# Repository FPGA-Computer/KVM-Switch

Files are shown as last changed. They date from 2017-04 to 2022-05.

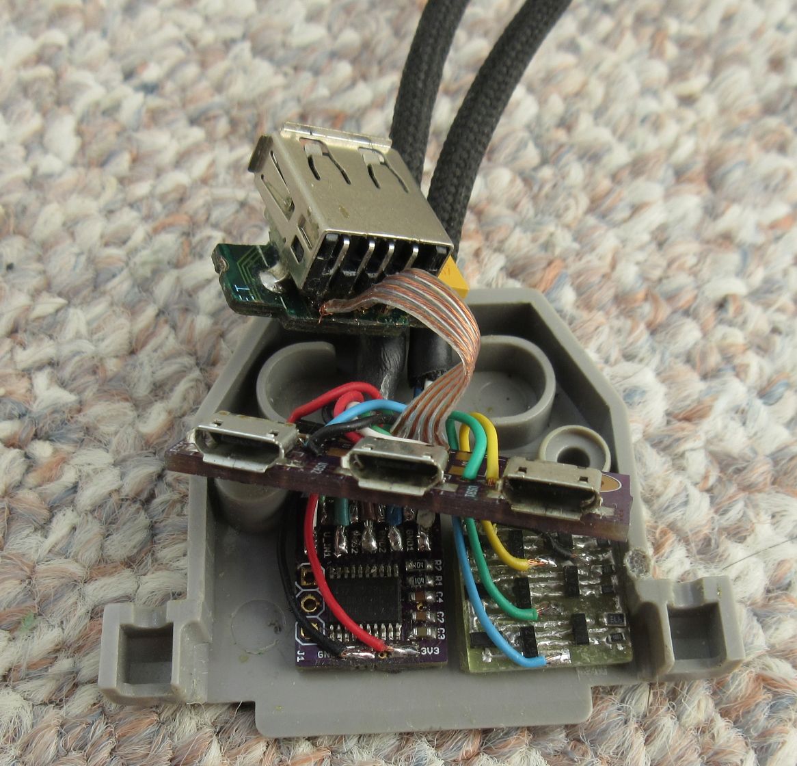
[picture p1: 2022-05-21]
Hardware/KVM boards.jpg

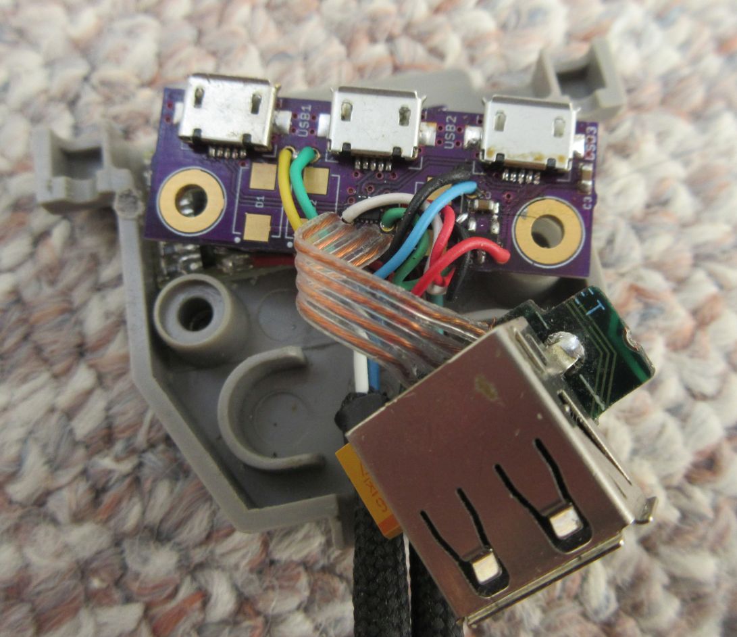
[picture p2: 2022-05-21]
Hardware/KVM boards - top.jpg

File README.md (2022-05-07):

KVM Switch
built from $5 HDMI switch + custom hardware

Details: https://hw-by-design.blogspot.com/2018/07/low-cost-kvm-switch.html

Hardware/ - Eagle CAD schematic, PCB, Sketchup 3D model (zipped)
Firmware/ - STM8S003 firmware source code for hotkey
KVM-Hotkey/ - initial test code I used during development.  
Included here for archive and completeiness because of my hosting changes.

Firmware written by me are licensed under GPL 3.0. 
Additional incorporated code are under their own licenses.

Hardware is licensed under CC BY-4.0

https://creativecommons.org/licenses/by/4.0/

Updates: change to Right CTRL key as hotkey.

Updates:

- Optional active or'ing circuit to replace Schottky diodes for lower voltage drops.

Or'ing circuit imspired by RPi 3 Model B rev. 1.2 USB power circuit. The matching transistor pair is
not needed - verified by simulation.  Voltage drop (roughly 50mV @0.5A). The circuit can share current
from multiple USB supplies.

- new USB Mux-v0.2 PCB layout with larger wiring pads, pads for optional or'ing circuit

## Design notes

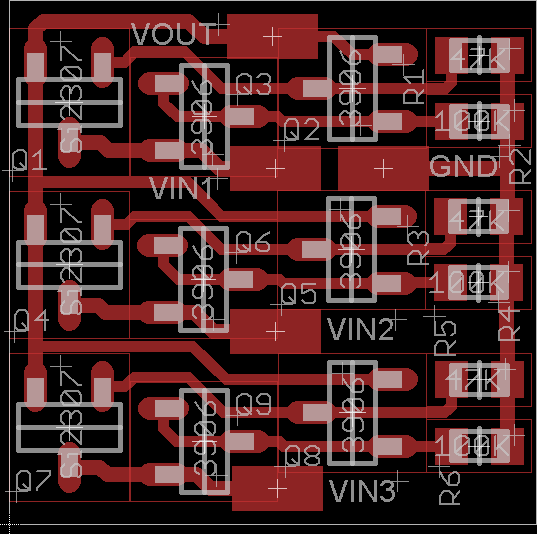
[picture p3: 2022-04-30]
Hardware/Acive Or'ing (optional)/active or'ing PCB.png

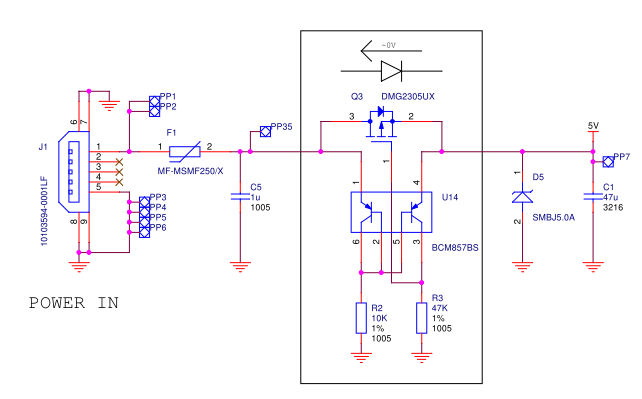
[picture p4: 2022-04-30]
Hardware/Acive Or'ing (optional)/RPi3 Model B or'ing circuit.png

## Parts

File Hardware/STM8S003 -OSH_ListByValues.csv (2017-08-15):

Qty | Value | Part Num | Package | Parts
2 | 0.1uF | 0.1uF X7R 0603 | CAPC1608X92N | C3, C4
1 | 1uF | 1uF X5R/X7R 0603 | CAPC1608X92N | C2
2 | 100K | 100K 0603 | RESC1608X55N | R1, R2
1 | STM8S003F3 | STM8S003F3 | TSSOP20 | U1
1 | SWIM Debug | 1x3 header for debugger | 1X03 | J1
1 | PCB | Ordering: https://oshpark.com/shared_projects/IDmovVvi

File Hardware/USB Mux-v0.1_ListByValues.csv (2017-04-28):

Qty | Value | Part Num | Package | Parts
3 |  | SMT MICRO USB CONNECTOR | USB-AB-MICRO-SMD_V03_SMT | USB1, USB2, USB3
1 | 0.1uF | 0U1 0603 | CAPC1608X92N | C1
2 | 1uF | 1UF 0603 | CAPC1608X92N | C2, C3
3 | MBRS140 | MBRS140 | DIOM5436X265N | D1, D2, D3
1 | NCN9252 | NCN9252 | UQN12 | U1
1 | XC6206P332MR | XC6206P332MR | SOT95P280X135-3N | U2 | Alternative: MCP1700T-3302E/TT
1 | PCB |  |  |  | https://oshpark.com/shared_projects/noy8f3xy

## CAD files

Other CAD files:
Firmware/hotkey.stp
Firmware/hotkey_Programmer/hotkey_STVP.stp
KVM-Hotkey/hotkey.stp

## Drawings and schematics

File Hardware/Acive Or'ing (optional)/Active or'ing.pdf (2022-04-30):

A

A

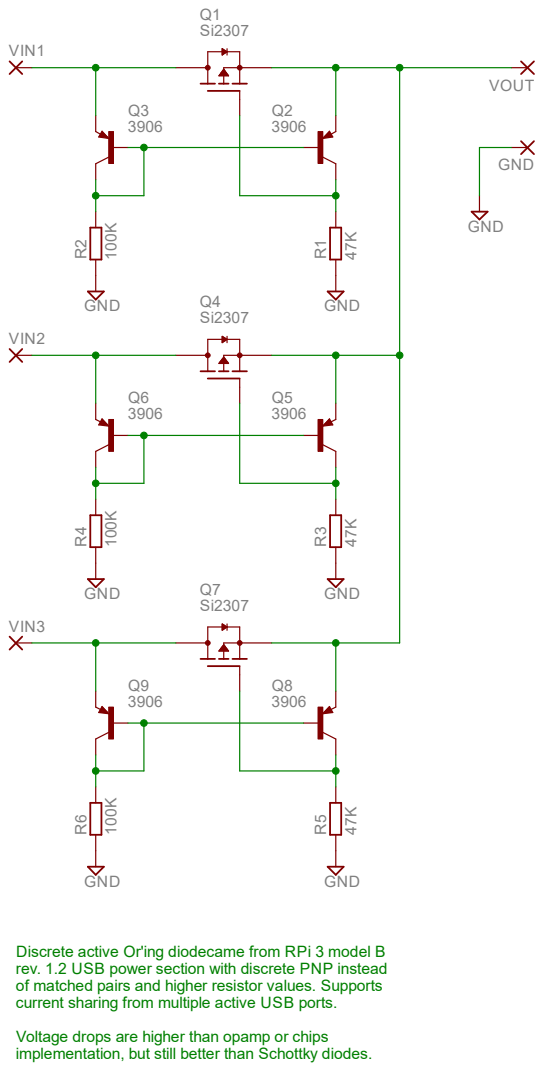
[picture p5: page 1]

Discrete active Or'ing diodecame from RPi 3 model B
rev. 1.2 USB power section with discrete PNP instead
of matched pairs and higher resistor values. Supports
current sharing from multiple active USB ports.

Copyright 2022 (c) by K. C. Lee
Licensed under CC BY-4.0

Voltage drops are higher than opamp or chips
implementation, but still better than Schottky diodes.

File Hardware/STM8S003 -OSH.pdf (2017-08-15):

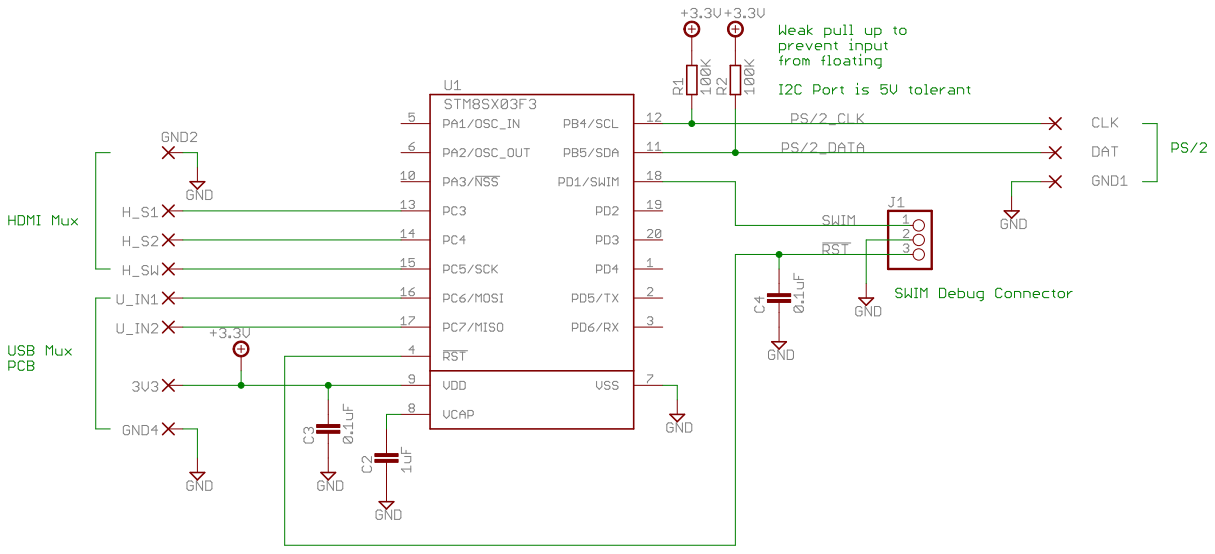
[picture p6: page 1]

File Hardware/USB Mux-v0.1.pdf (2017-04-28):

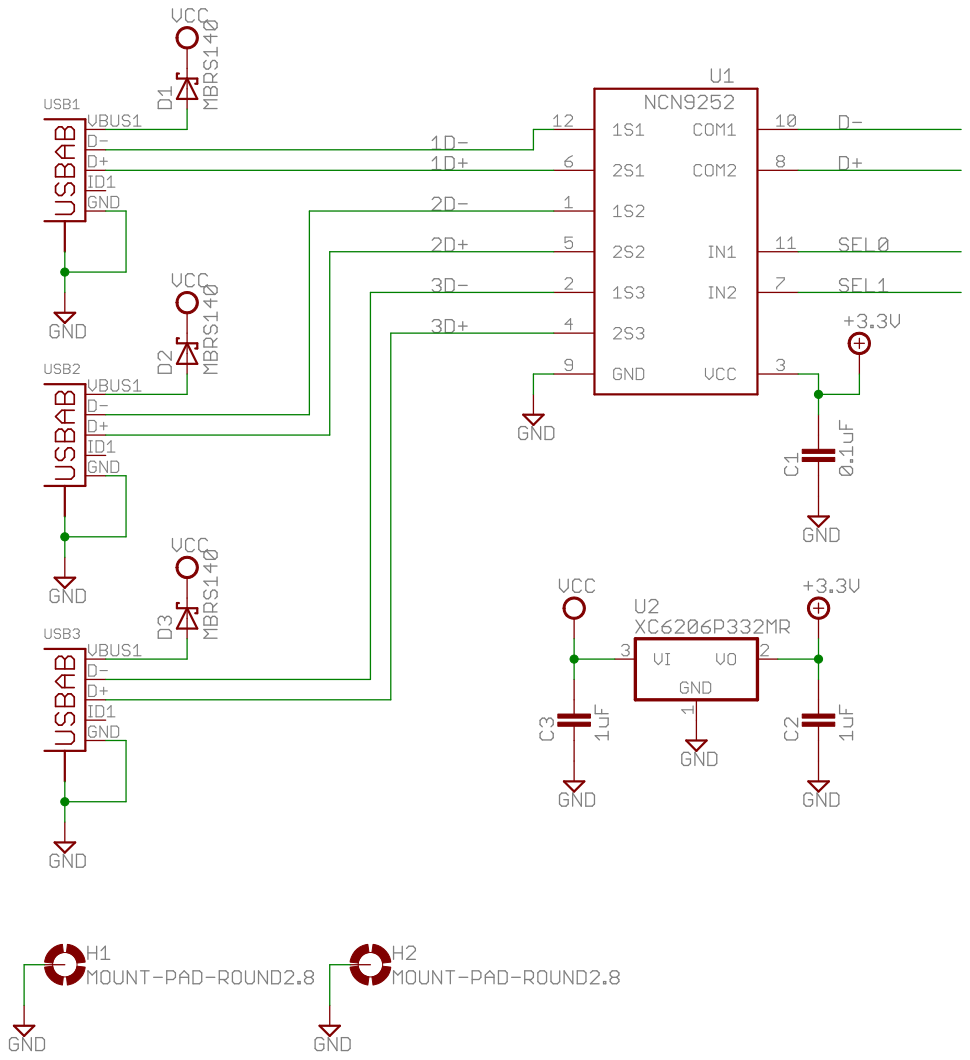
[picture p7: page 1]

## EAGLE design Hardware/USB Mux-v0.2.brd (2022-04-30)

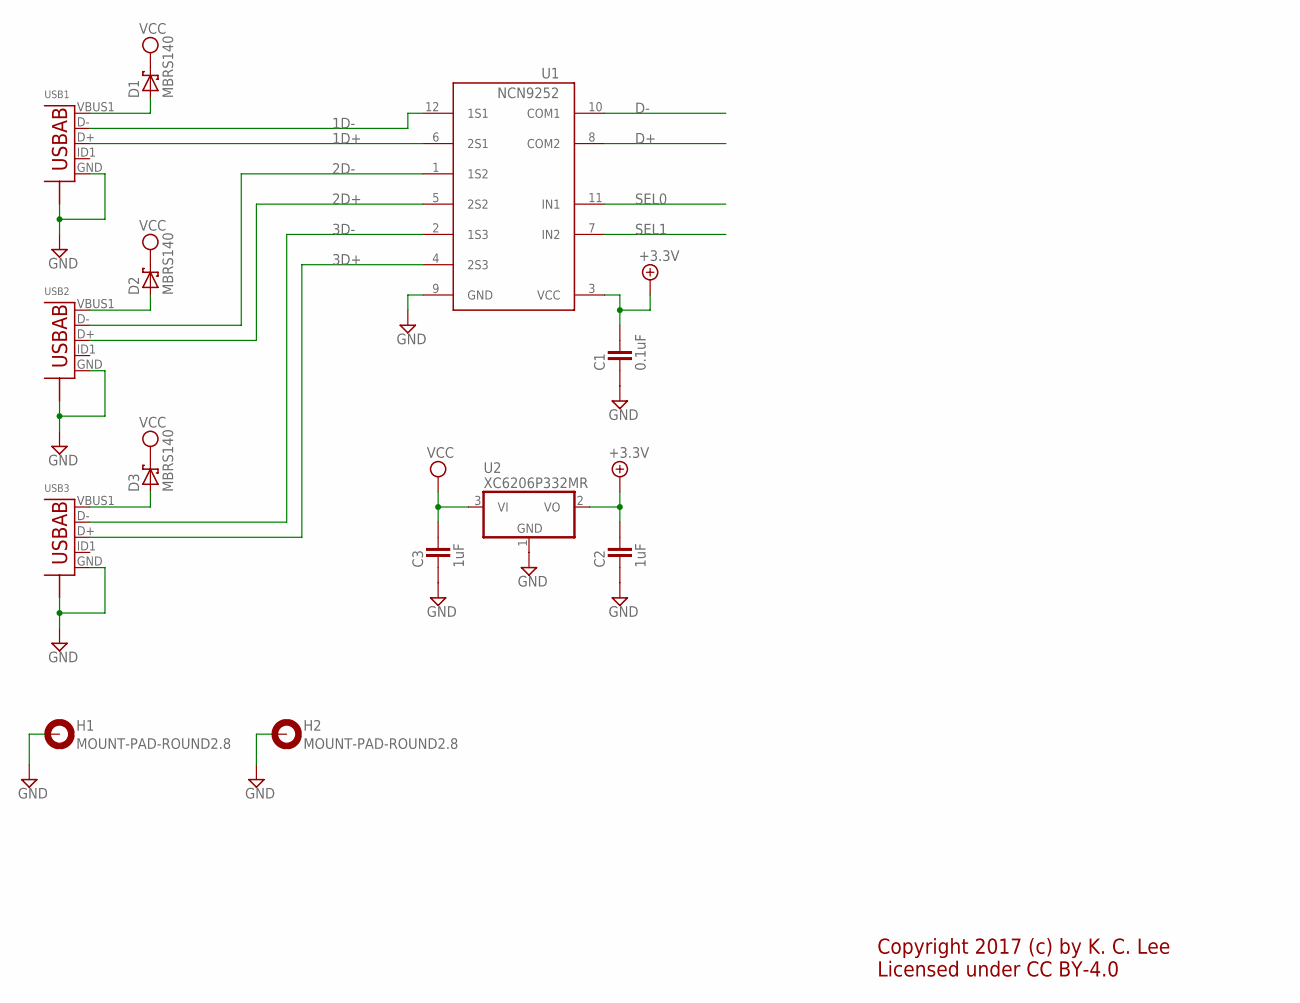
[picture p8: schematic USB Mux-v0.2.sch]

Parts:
C1: 0.1uF; CAPC1608X92N; PARTNO 0U1 0603
C2, C3: 1uF; CAPC1608X92N; PARTNO 1UF 0603
D1, D2, D3: MBRS140; DIOM5436X265N; PARTNO MBRS140
H1, H2: MOUNT-PAD-ROUND2.8; 2,8-PAD; PARTNO *
U1: NCN9252; UQN12; PARTNO NCN9252
U2: XC6206P332MR; SOT95P280X135-3N; PARTNO XC6206P332MR
USB1, USB2, USB3: USB-ABBG-ORG; USB-AB-MICRO-SMD_V03_SMT; PARTNO SMT MICRO USB CONNECTOR

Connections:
1D+: U1.6 (2S1), USB1.D+
1D-: U1.12 (1S1), USB1.D-
2D+: U1.5 (2S2), USB2.D+
2D-: U1.1 (1S2), USB2.D-
3D+: U1.4 (2S3), USB3.D+
3D-: U1.2 (1S3), USB3.D-
+3.3V: C1.2, C2.2, U1.3 (VCC), U2.2 (VO)
D+: U1.8 (COM2)
D-: U1.10 (COM1)
GND: C1.1, C2.1, C3.1, H1.B2,8, H2.B2,8, U1.9 (GND), U2.1 (GND), USB1.GND, USB1.S1 (S), USB1.S2 (S), USB1.S3 (S), USB1.S4 (S), USB2.GND, USB2.S1 (S), USB2.S2 (S), USB2.S3 (S), USB2.S4 (S), USB3.GND, USB3.S1 (S), USB3.S2 (S), USB3.S3 (S), USB3.S4 (S)
unnamed: D3.A, USB3.VBUS1 (VBUS)
unnamed: D2.A, USB2.VBUS1 (VBUS)
unnamed: D1.A, USB1.VBUS1 (VBUS)
SEL0: U1.11 (IN1)
SEL1: U1.7 (IN2)
VCC: C3.2, D1.K, D2.K, D3.K, U2.3 (VI)

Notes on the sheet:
Copyright 2017 (c) by K. C. Lee Licensed under CC BY-4.0

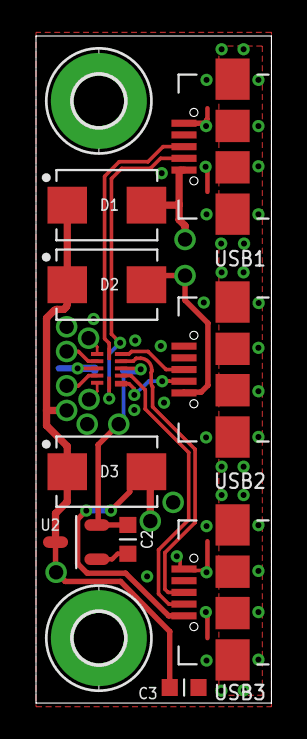
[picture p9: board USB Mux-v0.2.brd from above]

Board: 2 copper layers, 13.1 x 37.1 mm, 13 parts (1 on the bottom side), 12 nets.

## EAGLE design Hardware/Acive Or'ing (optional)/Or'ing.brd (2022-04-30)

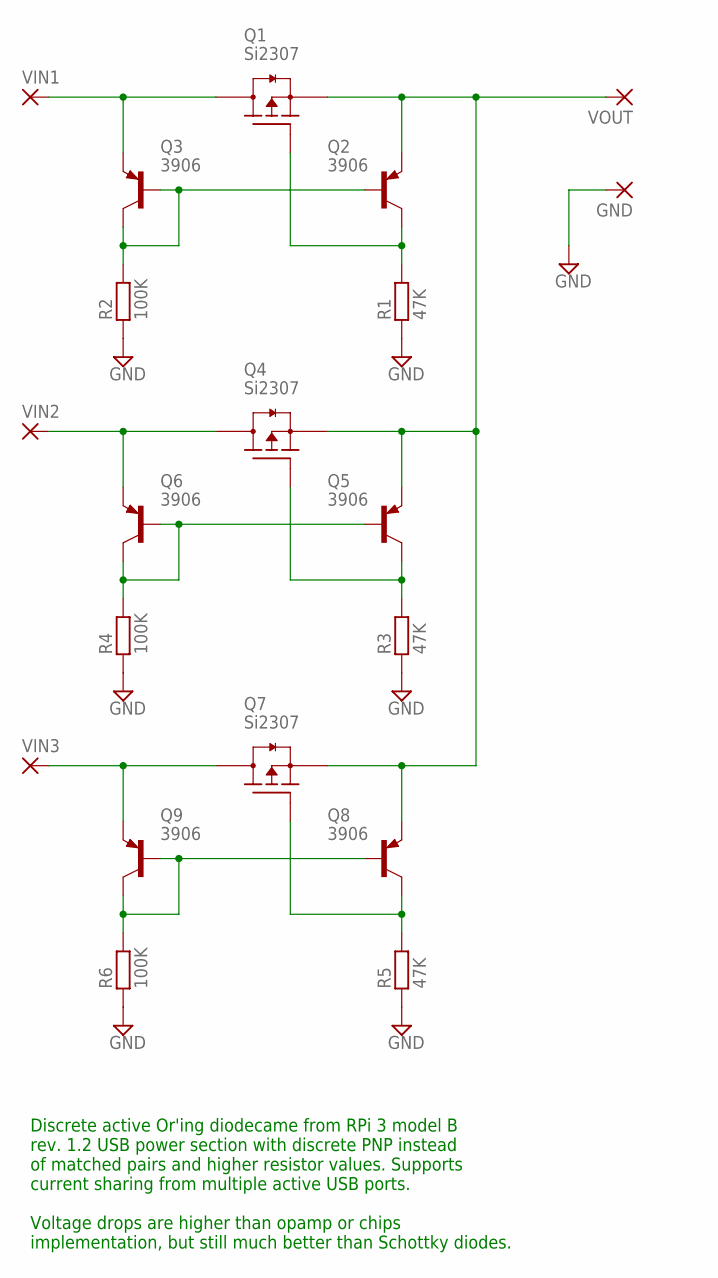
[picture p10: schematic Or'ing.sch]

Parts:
GND: SMD2; SMD1,27-2,54
Q1, Q4, Q7: Si2307; SOT95P280X135-3N
Q2, Q3, Q5, Q6, Q8, Q9: 3906; SOT95P280X135-3N
R1, R3, R5: 47K; RESC1608X55N
R2, R4, R6: 100K; RESC1608X55N
VIN1, VIN2, VIN3: SMD2; SMD1,27-2,54
VOUT: SMD2; SMD1,27-2,54

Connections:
GND: GND.1, R1.1, R2.1, R3.1, R4.1, R5.1, R6.1
unnamed: Q1.2 (S), Q2.2 (E), Q4.2 (S), Q5.2 (E), Q7.2 (S), Q8.2 (E), VOUT.1
unnamed: Q1.3 (D), Q3.2 (E), VIN1.1
unnamed: Q1.1 (G), Q2.3 (C), R1.2
unnamed: Q2.1 (B), Q3.1 (B), Q3.3 (C), R2.2
unnamed: Q4.3 (D), Q6.2 (E), VIN2.1
unnamed: Q4.1 (G), Q5.3 (C), R3.2
unnamed: Q5.1 (B), Q6.1 (B), Q6.3 (C), R4.2
unnamed: Q7.3 (D), Q9.2 (E), VIN3.1
unnamed: Q7.1 (G), Q8.3 (C), R5.2
unnamed: Q8.1 (B), Q9.1 (B), Q9.3 (C), R6.2

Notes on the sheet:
Discrete active Or'ing diodecame from RPi 3 model B rev. 1.2 USB power section with discrete PNP instead of matched pairs and higher resistor values. Supports current sharing from multiple active USB ports. Voltage drops are higher than opamp or chips implementation, but still much better than Scho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

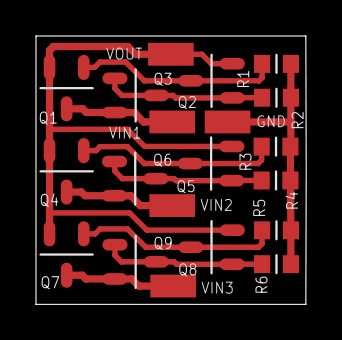
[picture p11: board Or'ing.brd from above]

Board: 2 copper layers, 15.0 x 14.9 mm, 20 parts (0 on the bottom side), 11 nets.

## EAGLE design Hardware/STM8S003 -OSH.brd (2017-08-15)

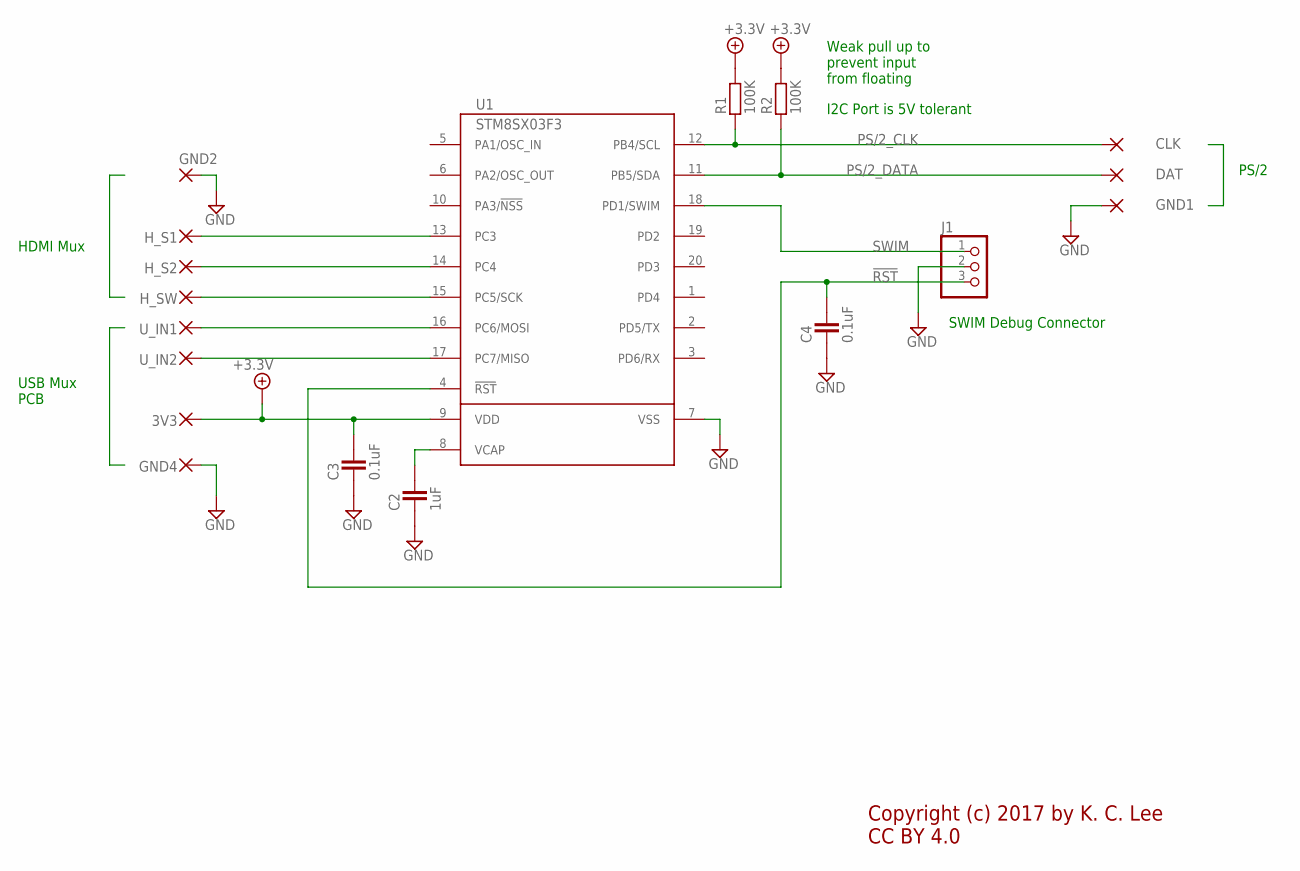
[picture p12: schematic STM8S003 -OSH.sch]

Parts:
3V3: SMD2; SMD1,27-2,54
C2: 1uF; CAPC1608X92N
C3, C4: 0.1uF; CAPC1608X92N
CLK: SMD2; SMD1,27-2,54
DAT: SMD2; SMD1,27-2,54
GND1, GND2, GND4: SMD2; SMD1,27-2,54
H_S1, H_S2: SMD2; SMD1,27-2,54
H_SW: SMD2; SMD1,27-2,54
J1: PINHD-1X3; 1X03
R1, R2: 100K; RESC1608X55N
U1: STM8SX03F3; TSSOP20
U_IN1, U_IN2: SMD2; SMD1,27-2,54

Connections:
!RST: C4.2, J1.3, U1.4 (!RST)
+3.3V: 3V3.1, C3.2, R1.2, R2.2, U1.9 (VDD)
GND: C2.1, C3.1, C4.1, GND1.1, GND2.1, GND4.1, J1.2, U1.7 (VSS)
unnamed: C2.2, U1.8 (VCAP)
unnamed: U1.17 (PC7/MISO), U_IN2.1
unnamed: U1.16 (PC6/MOSI), U_IN1.1
unnamed: H_SW.1, U1.15 (PC5/SCK)
unnamed: H_S1.1, U1.13 (PC3)
unnamed: H_S2.1, U1.14 (PC4)
PS/2_CLK: CLK.1, R1.1, U1.12 (PB4/SCL)
PS/2_DATA: DAT.1, R2.1, U1.11 (PB5/SDA)
SWIM: J1.1, U1.18 (PD1/SWIM)

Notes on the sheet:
Copyright (c) 2017 by K. C. Lee CC BY 4.0
HDMI Mux
USB Mux PCB
PS/2
SWIM Debug Connector
Weak pull up to prevent input from floating
I2C Port is 5V tolerant

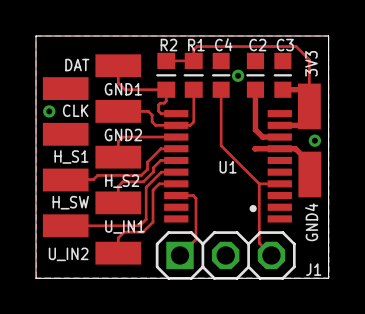
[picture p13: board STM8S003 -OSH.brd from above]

Board: 2 copper layers, 16.3 x 13.5 mm, 18 parts (0 on the bottom side), 12 nets.

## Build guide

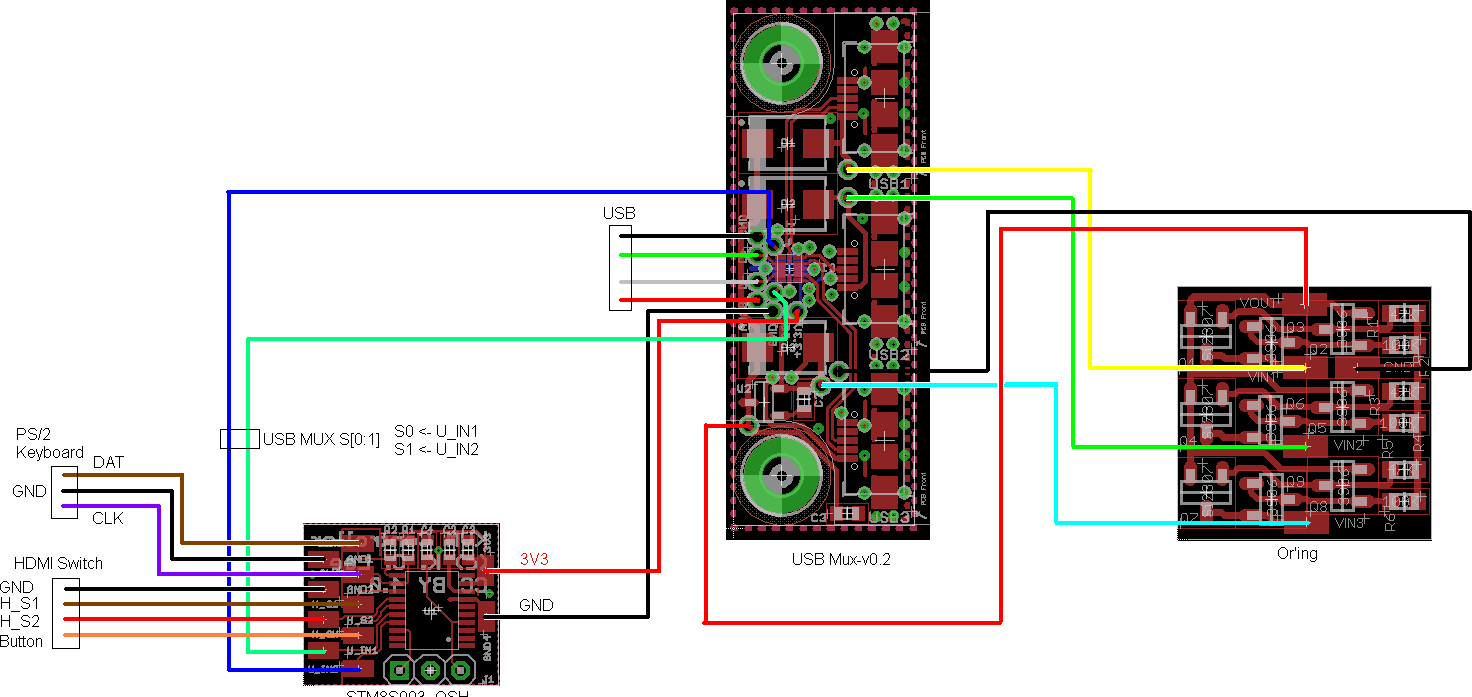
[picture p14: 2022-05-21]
Hardware/Wiring diagram.png

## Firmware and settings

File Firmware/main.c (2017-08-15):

/*
 * main.c
 *
 * Created: April-28-17, 5:42:00 PM
 *  Author: K. C. Lee
 * Copyright (c) 2017 by K. C. Lee
 
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
 If not, see http://www.gnu.org/licenses/gpl-3.0.en.html 
 */ 

#include "hardware.h"

void main(void)
{
	Init_Hardware();
	
	while(1)
	{
		PS2_Task();
	}
}

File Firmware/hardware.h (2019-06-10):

/*
 * hardware.h
 *
 * Created: 22/12/2016 6:03:25 AM
 *  Author: K. C. Lee
 * Copyright (c) 2016 by K. C. Lee
 
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
 If not, see http://www.gnu.org/licenses/gpl-3.0.en.html 
 */ 

#ifndef HARDWARE_H_
#define HARDWARE_H_

#ifndef __CSMC__
#define __CSMC__
#endif
#define STM8S003

#include "stm8s.h"
//#include <stdio.h>

// STM8S003F3P6
enum _PA { PA1=0x02, PA2=0x04, PA3=0x08 };
enum _PB { PB4=0x10, PB5=0x20 };
enum _PC { PC3=0x08, PC4=0x10, PC5=0x20, PC6=0x40, PC7=0x80 };
enum _PD { PD1=0x02, PD2=0x04, PD3=0x08, PD4=0x10, PD5=0x20, PD6=0x40 };

#include "irq.h"

#define PS2_CLK									PB4
#define PS2_DATA								PB5
#define PS2_PORT								GPIOB

#define HDMI_S1									PC3
#define HDMI_S2									PC4

#define HDMI_SW									PC5

#define USB_IN1									PC6
#define USB_IN2									PC7
#define HDMI_PORT								GPIOC

#define HDMI_NO_CONNECT					0x01
#define USB_NO_CONNECT					0x00

#define HDMI_SEL_MASK						(HDMI_S1 | HDMI_S2)
#define USB_SEL_MASK						(USB_IN1 | USB_IN2)

#define HDMI_SHIFT							3
#define USB_SHIFT								6

#define PS2_KBD									0x40
#define PS2_CMD									0x00

#define PS2_KBD_BITS						10
#define PS2_CMD_BITS						11

#define PS2_BIT_TIMEOUT					1500		// us

enum Key_States
{
	PS2_Idle = 0,
	PS2_KBD_1 = PS2_KBD+1,
	PS2_KBD_LAST = PS2_KBD_1+PS2_KBD_BITS,
	PS2_CMD_1 = PS2_CMD+1,
	PS2_CMD_LAST = PS2_CMD_1+PS2_CMD_BITS
};

enum Hotkey_States
{
	HK_Idle,
	HK_KeyMake_1,
	HK_KeyBreak_1,
	HK_KeyMake_2
};

enum KeyAttrib
{
	Key_Regular = 0x00,
	Key_Release = 0x01,
	Key_Extend	= 0x02
};

typedef struct
{
	volatile	uint16_t	ScanCode;
						uint8_t 	State;
						uint8_t		Attrib;
	volatile 	uint8_t		Avail;
} KBD_States;

#define PS2_KBD_CODE_EXTENDED   0xe0
#define PS2_KBD_CODE_RELEASE    0xf0

// CTRL
#define HOTKEY_SCANCODE					0x14

#define RCTRL		// Hotkey: Right CRTL

#ifdef RCTRL		// Hotkey: Right CRTL
#define HOTKEY_MAKE							((ScanCode == HOTKEY_SCANCODE) && (Hotkeys.KeyAttr==Key_Extend))
#define HOTKEY_RELEASE					((ScanCode == HOTKEY_SCANCODE) && (Hotkeys.KeyAttr==(Key_Extend|Key_Release)))
#else						// Hotkey: Left CRTL
#define HOTKEY_MAKE							((ScanCode == HOTKEY_SCANCODE) && !Hotkeys.KeyAttr)
#define HOTKEY_RELEASE					((ScanCode == HOTKEY_SCANCODE) && (Hotkeys.KeyAttr==Key_Release))
#endif

#define HOTKEY_RELEASE_DELAY		ms_TO_TICKS(250)
#define HOTKEY_WAIT_DELAY				ms_TO_TICKS(200)
#define HOTKEY_USB_WAIT					ms_TO_TICKS(50)
#define HDMI_SW_DELAY						ms_TO_TICKS(100)

typedef struct
{
	uint8_t State;
	uint8_t KeyAttr;
} Hotkey_State;

#define TIM4_PSCR								3
#define TIM4_ARR 								200
#define MILLI_DIVIDER_RELOAD		100

// 16MHz/2^TIM4_PSCR/TIM4_ARR = 10kHz (100us per tick)
// 10kHz/MILLI_DIVIDER_RELOAD = 100Hz (10ms per tick)

// Minimum delay
#define us_TO_TICKS(X)					((X)/100)
#define ms_TO_TICKS(X)					((X)/10)

void Init_Hardware(void);
void PS2_Task(void);

// uart 115200
#define UART_BAUD								115200UL
#define UART_BRR_DIV						((int)(HSI_VALUE/UART_BAUD+0.5))
#define UART_BRR1								((UART_BRR_DIV & 0x0ff0)>>4)
#define UART_BRR2								(((UART_BRR_DIV & 0xf000)>>8)|(UART_BRR_DIV & 0x0f))

void Init_Serial(void);
uint8_t GetC(void);
void PutC(uint8_t ch);
void Puthex2(uint8_t n);
void Puthex4(uint16_t n);
void NewLine(void);

#define Poll_Serial()	(UART1->SR & UART1_SR_RXNE)
#define Get_Char()		(UART1->DR)

#endif

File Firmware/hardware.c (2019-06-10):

/*
 * hardware.c
 *
 * Created: April-28-17, 5:42:00 PM
 *  Author: K. C. Lee
 * Copyright (c) 2017 by K. C. Lee
 
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
 If not, see http://www.gnu.org/licenses/gpl-3.0.en.html 
 */ 

#include "hardware.h"

KBD_States PS2;
Hotkey_State Hotkeys;

uint8_t Micro_Timer1,Milli_Timer1,Milli_Timer2,Milli_Divider;

const uint8_t Mux_Tbl[]=
{
	// 		USB Mux								HDMI Mux
	0x01 << USB_SHIFT,	// 	00	Output 1
	0x00 << USB_SHIFT,	//	01	No connect
	0x02 << USB_SHIFT,	//	10	Output 2
	0x03 << USB_SHIFT		//	11	Output 3
};

void Init_Hardware(void)
{
	CLK->CKDIVR = 0;										// Clk divider, CPU divider = 1
	EXTI->CR1 = (0x02 << 2);						// PB2 Interrupt: Falling edge
	PS2_PORT->CR2 = PS2_CLK;						// Enable PS2_CLK interrupt
	
	// Button: open drain, USB: Push/pull; HDMI_S1, HDMI_S2: input+pullup
	HDMI_PORT->DDR = HDMI_SW|USB_IN1|USB_IN2;
	HDMI_PORT->CR1 = HDMI_S1|HDMI_S2|USB_IN1|USB_IN2;
	
	// unused GPIO defaults to output, push-pull
	GPIOA->CR1 = GPIOA->DDR = PA1|PA2|PA3;
	GPIOD->CR1 = GPIOD->DDR = PD2|PD3|PD4;
	
	// tim4 8-bit timer: Auto-reload, update = over/under flow, Counter enable
	TIM4->CR1 = TIM4_CR1_ARPE|TIM4_CR1_URS|TIM4_CR1_CEN;

	TIM4->IER = TIM4_IER_UIE;					// Update IRQ enable
	TIM4->PSCR = TIM4_PSCR;						// TIM4: 16MHz/2^TIM4_PSCR
	TIM4->ARR = TIM4_ARR;							// Auto-reload
	
	// IRQ4 (PORTB PS2 CLK) = level 3 (high)
	ITC->ISPR2 = 0x03;
	// Rest of IRQ level 0 (low)
	ITC->ISPR1 = ITC->ISPR3 = ITC->ISPR4 = ITC->ISPR5 = ITC->ISPR6 = 0x00;
	
	PS2.State = PS2_Idle;
	
	Hotkeys.State = HK_Idle;
	Hotkeys.KeyAttr = 0;
	// Turn on interrupts
	rim();
}

// Low priority timer interrupt: 10kHz
@far @interrupt void TIM4_IRQ(void)
{
	TIM4->SR1 &= ~TIM4_SR1_UIF;				// Clear update IRQ
	
	if(Micro_Timer1)
		Micro_Timer1--;

	if(Milli_Divider)
		Milli_Divider--;
	else
	{																	// 100Hz interrupt
		if(Milli_Timer1)
			Milli_Timer1--;			

		if(Milli_Timer2)								// HDMI button
			Milli_Timer2--;
		else
			HDMI_PORT->ODR |= HDMI_SW;		// Clear select button

		Milli_Divider = MILLI_DIVIDER_RELOAD;
	}
}

@far @interrupt void PORTB_IRQ(void)
{		
	if((PS2.State == PS2_Idle)||(!Micro_Timer1))	// Start bit or resynchronized
	{
		// rewind timer
		Micro_Timer1 = us_TO_TICKS(PS2_BIT_TIMEOUT);
		// first bit determines source: keyboard or PC
		PS2.State = (PS2_PORT->IDR & PS2_DATA)?PS2_CMD_1:PS2_KBD_1;
	}
	else
	{	
		if(PS2.State++ & PS2_KBD)											// Scan/respond code
		{
			if(PS2.State == PS2_KBD_LAST)
			{	
				PS2.Avail = 1;
				PS2.State = PS2_Idle;
			}
			else
			{
				PS2.ScanCode >>= 1;
				
				if(PS2_PORT->IDR & PS2_DATA)
					PS2.ScanCode |= 0x200;
			}
		}
		else																					// Ignore Cmd to keyboard
			if(PS2.State == PS2_CMD_LAST)
				PS2.State = PS2_Idle;
	}
}

// high level polling task
void PS2_Task(void)
{
	uint16_t ScanCode, Parity;
	uint8_t HDMI, USB;
	
	if(PS2.Avail)
	{
		// Critical section
		sim();
		ScanCode = PS2.ScanCode;
		PS2.Avail = 0;
		rim();
		
		Parity = PS2.ScanCode & 0x01;	
		ScanCode = (ScanCode >> 1) & 0xff;
		
		if (ScanCode == PS2_KBD_CODE_RELEASE)
			Hotkeys.KeyAttr |= Key_Release;
		else if (ScanCode == PS2_KBD_CODE_EXTENDED)
			Hotkeys.KeyAttr |= Key_Extend;
		else
		{
			switch(Hotkeys.State)
			{
				case HK_Idle:					// wait for hot key press
				  if(HOTKEY_MAKE)
					{
						Hotkeys.State = HK_KeyMake_1;
						Milli_Timer1 = HOTKEY_RELEASE_DELAY;
						return;
					}
					break;
					
				case HK_KeyMake_1:		// wait for hot key release instead of hold
				  if(HOTKEY_RELEASE && Milli_Timer1)
					{
						Hotkeys.KeyAttr = 0;
						Hotkeys.State = HK_KeyBreak_1;
						Milli_Timer1 = HOTKEY_WAIT_DELAY;				
						return;
					}
					else
						Hotkeys.State = HK_Idle;
					break;
					
				case HK_KeyBreak_1:		// wait for hot key release
				  if(HOTKEY_MAKE && Milli_Timer1)
					{
						Hotkeys.State = HK_KeyMake_2;
						Milli_Timer1 = HOTKEY_RELEASE_DELAY;				
						return;
					}
					else
						Hotkeys.State = HK_Idle;
					break;
					
				case HK_KeyMake_2:		// wait for hot key press again
				  if(HOTKEY_RELEASE && Milli_Timer1)
					{	
						// Wait for USB to finish sending hot key release to host
						Milli_Timer1 = HOTKEY_USB_WAIT;
						
					  while(Milli_Timer1)
						  /* busy wait */;
					
						HDMI_PORT->ODR &= ~HDMI_SW;						// Press select button(active low)	
					  Milli_Timer2 = HDMI_SW_DELAY;					// hold for delay
					}
					else
						Hotkeys.State = HK_Idle;
					
					break;
			}

			// default to idle
			Hotkeys.State = HK_Idle;
			Hotkeys.KeyAttr = 0;
		}
	}
	
	HDMI = (HDMI_PORT->IDR & HDMI_SEL_MASK)>>HDMI_SHIFT;
	// HDMI Mux setting mapped to USB
	USB = Mux_Tbl[HDMI];
	
	// filters out inactive HDMI, update when USB is not adready the same port
	if(((HDMI!= HDMI_NO_CONNECT)&&(HDMI_PORT->ODR & USB_SEL_MASK)!= USB))
	{
		// Make the Read-Modify-Write I/O atomic
		sim();
		HDMI_PORT->ODR = (HDMI_PORT->ODR & HDMI_SW)|USB;
		rim();
	}
}

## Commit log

2017-04-28 Initial commit - PCB not tested
    [USB Connector.brd, USB Connector.sch, USB Mux-v0.1.brd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]
2017-08-15 Firmware added
    [STM8S003 -OSH.brd, STM8S003 -OSH.sch, STM8S003 -OSH_ListByValues.csv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]
2017-08-25 Add delay for USB hotkey release before switching
2018-07-31 Dead branch - Code used during development. Included here for archive due to hosting changes.
    [hotkey.stp]
2022-04-30 PCB update, optional or'ing circuit
    [Or'ing.brd, Or'ing.sch, USB Mux-v0.2.brd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]
2022-05-21 Add wiring diagram, pictures of PCB

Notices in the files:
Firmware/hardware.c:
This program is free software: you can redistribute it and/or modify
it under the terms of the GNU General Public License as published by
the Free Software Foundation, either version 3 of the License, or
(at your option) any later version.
